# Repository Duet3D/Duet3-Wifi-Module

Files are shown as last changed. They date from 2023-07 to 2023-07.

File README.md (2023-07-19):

# Duet3 Wifi Module
Plugin wifi module for Duet 3 6HC mainboards



Product Page:
[https://www.duet3d.com/duet3_wifi_module](https://www.duet3d.com/duet3_wifi_module)

Documentation is here:

[Duet 3 Wifi Module Documentation](https://docs.duet3d.com/Duet3D_hardware/Duet_3_family/Duet_3_Mainboard_6HC_Hardware_Overview#wifi-v102)

licensed under the "CERN-OHL-S v2" or any later version plus the "Additional Duet3D Licence Terms",
see https://github.com/Duet3D/Duet3-Mainboard-6HC/blob/master/LICENSE

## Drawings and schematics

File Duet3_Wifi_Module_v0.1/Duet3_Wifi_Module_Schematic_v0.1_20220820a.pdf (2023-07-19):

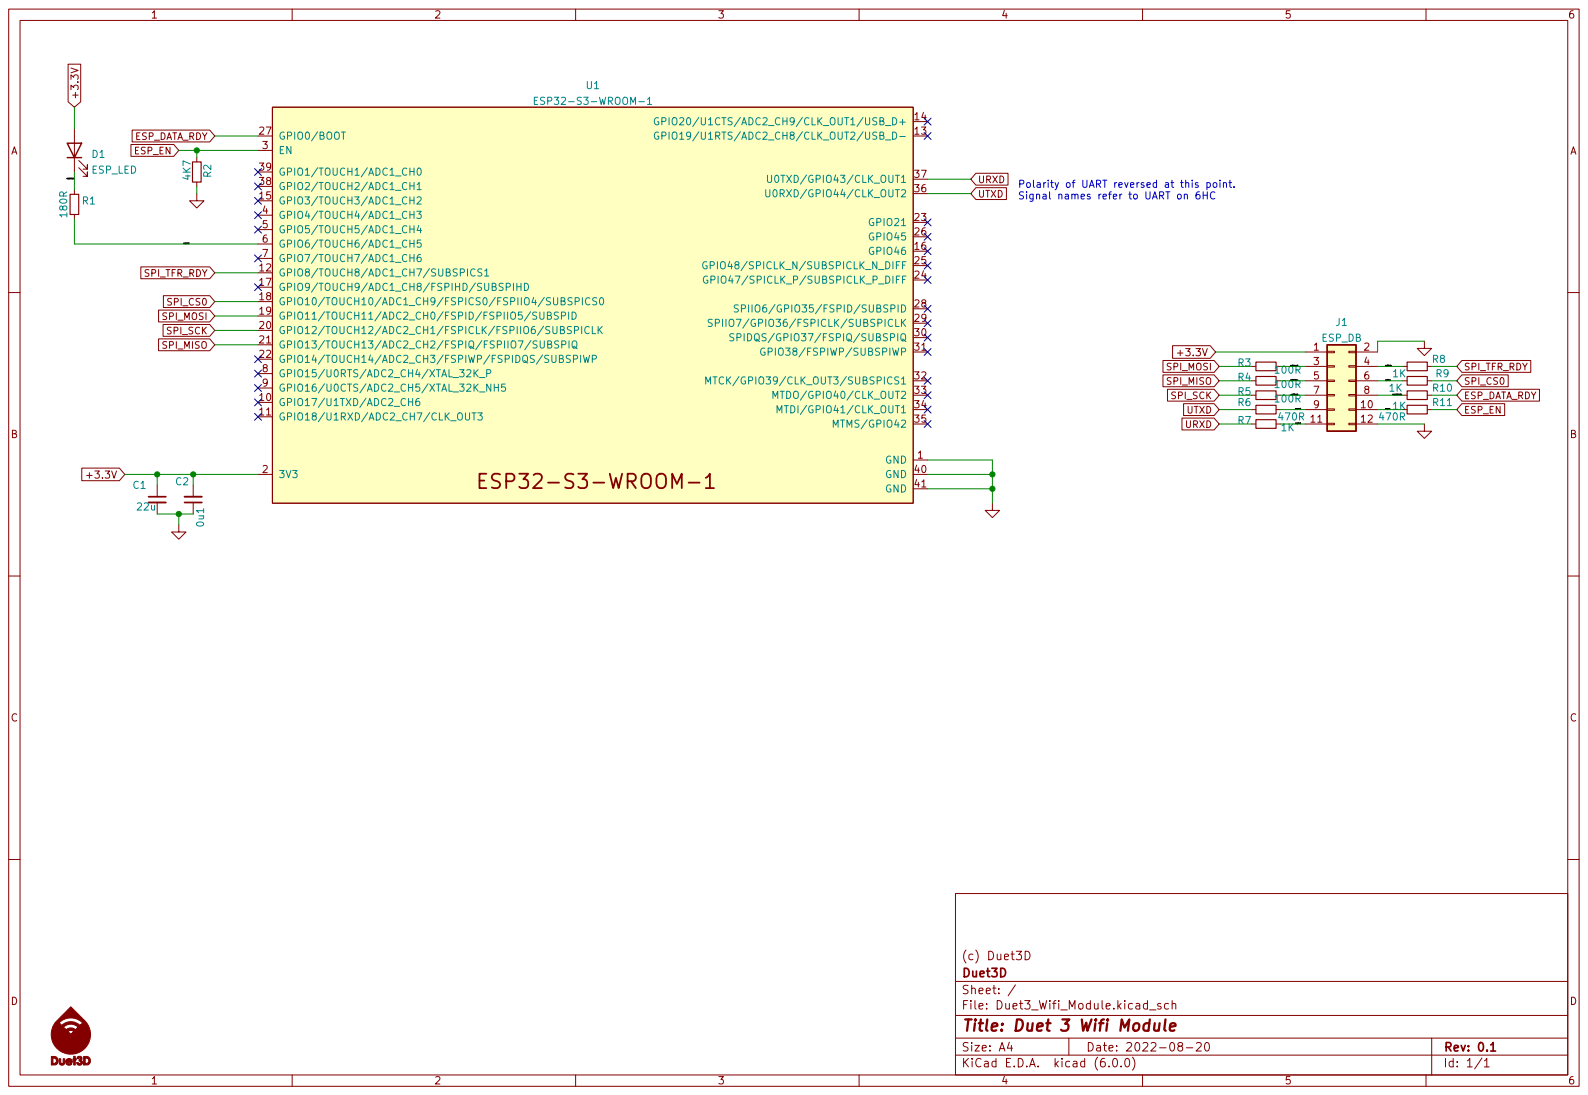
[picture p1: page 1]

spi1mosi Polarity of UART reversed at this point.
Signal names refer to UART on 6HC

Id: 1/1 Title: Duet 3 Wifi Module

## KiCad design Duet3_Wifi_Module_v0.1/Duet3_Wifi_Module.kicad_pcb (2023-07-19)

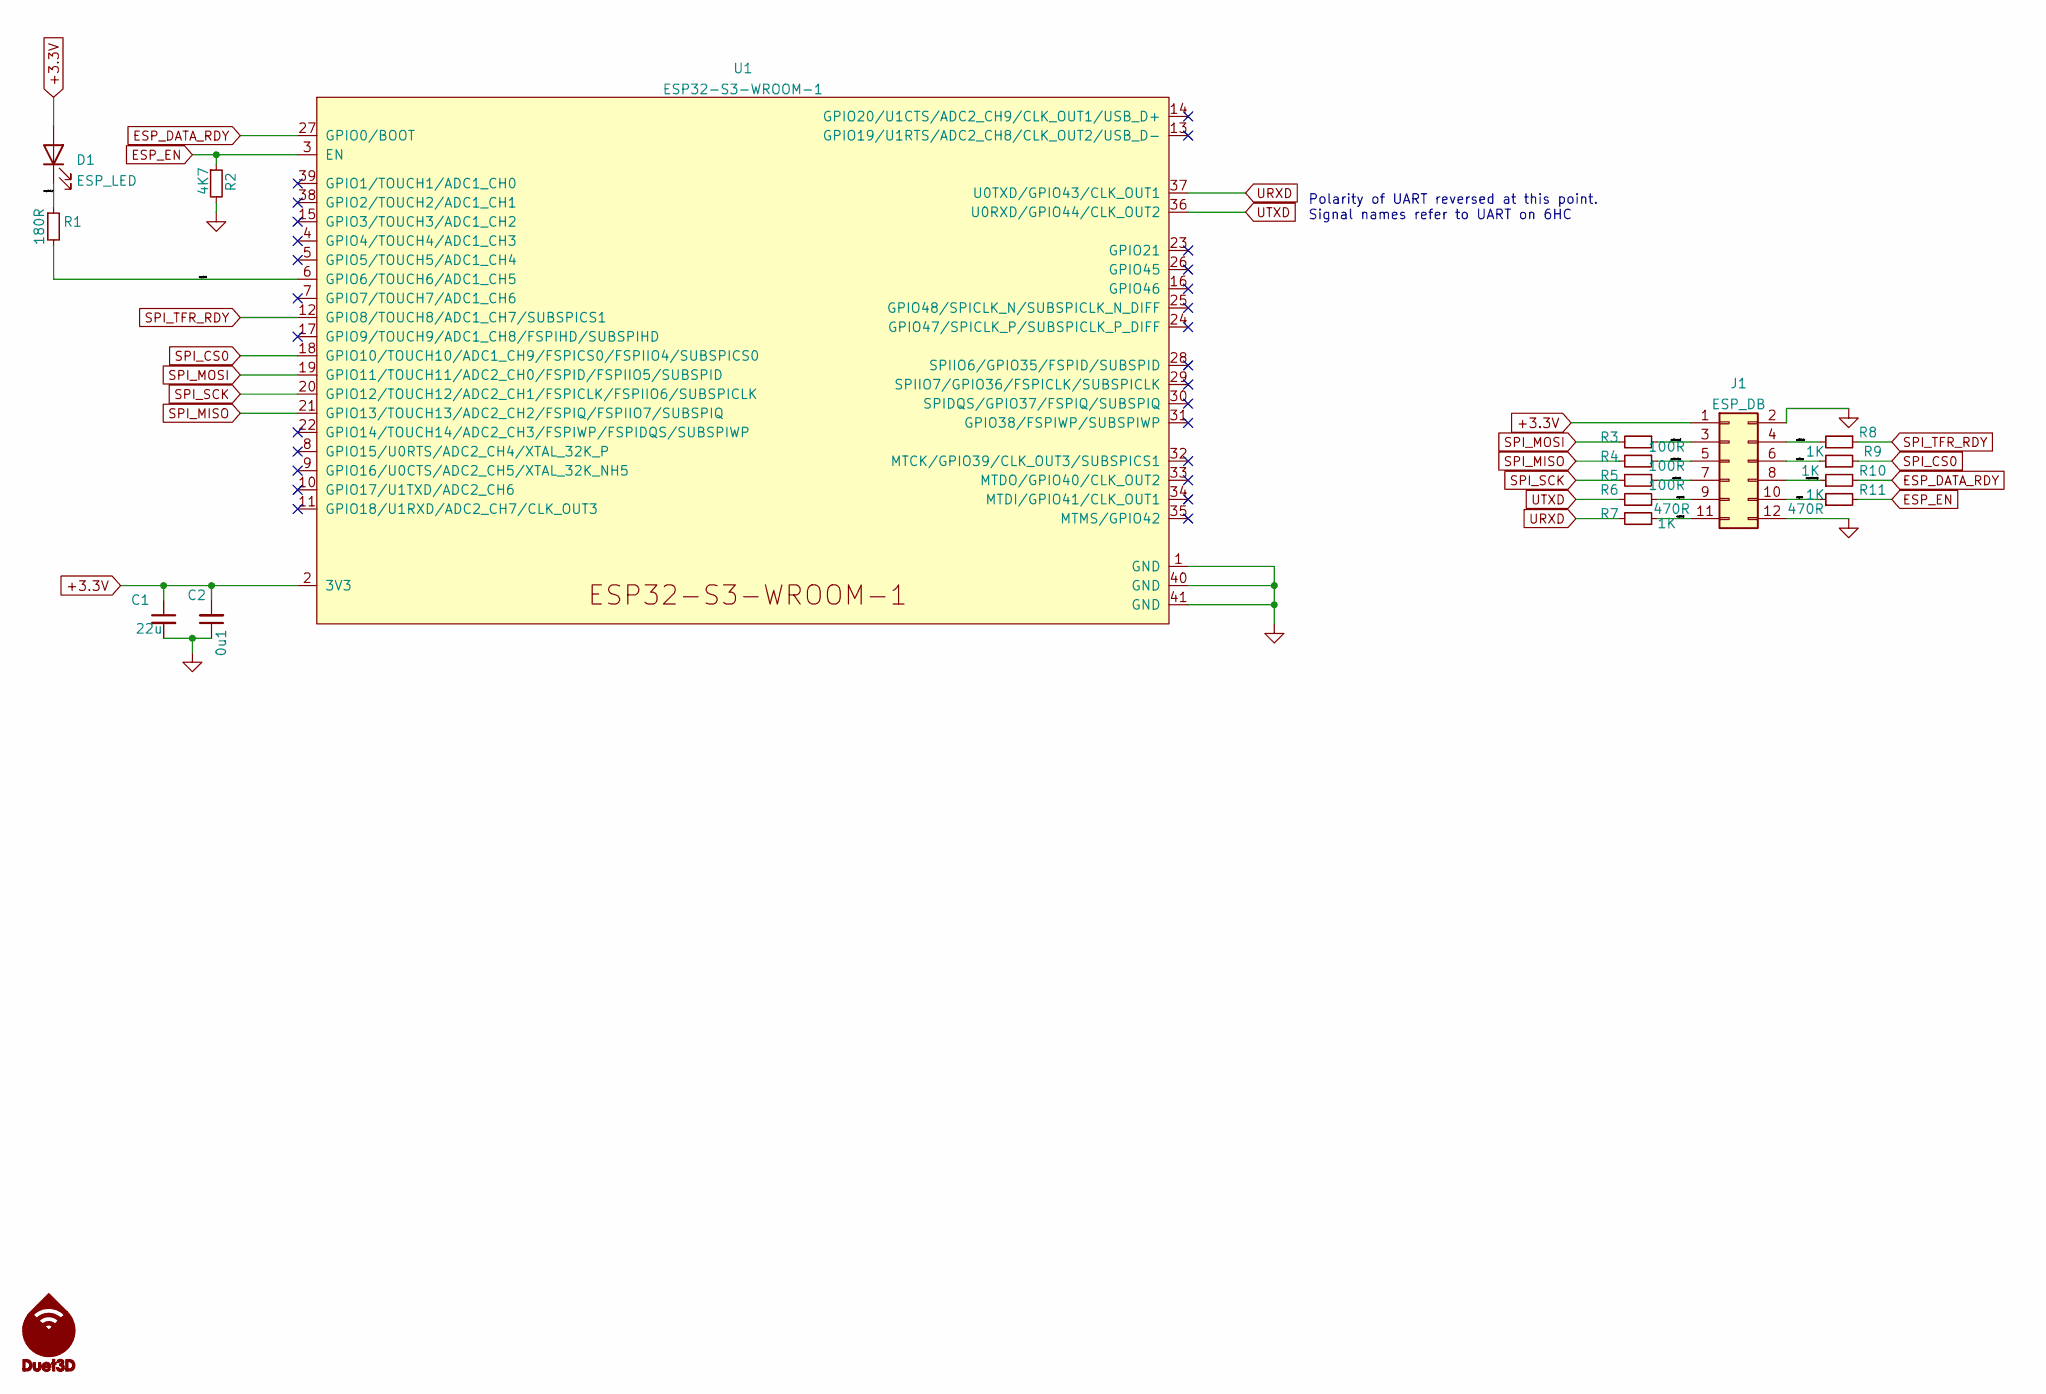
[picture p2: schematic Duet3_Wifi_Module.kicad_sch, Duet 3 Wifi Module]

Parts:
C1: 22u; C_0805_2012Metric; Part Number CL21A226MOQNNNE
C2: 0u1; C_0402_1005Metric_Wbry; Part Number CL05A104KP5NNNC
D1: ESP_LED; LED_0603_1608Metric; Part Number 150060VS75000 or equivalent Green
J1: ESP_DB; PinSocket_2x06_P2.54mm_Vertical
M1: Logo_Duet3d_New; LOGO_NEW_Duet3D_vertical_6mm; Part Number Virtual Component DNP
R1: 180R; R_0402_1005Metric_Wbry; Part Number RMCF0402FT180R
R2: 4K7; R_0402_1005Metric_Wbry; Part Number RK73H1ETTP4701F
R3, R4, R5: 100R; R_0402_1005Metric_Wbry; Part Number RK73H1ETTP1000F
R6, R11: 470R; R_0402_1005Metric_Wbry; Part Number RK73H1ETTP4700F
R7, R8, R9, R10: 1K; R_0402_1005Metric_Wbry; Part Number RK73H1ETTP1001F
U1: ESP32-S3-WROOM-1; ESP32-S3-WROOM-1U

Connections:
+3.3V: C1.1, C2.2, D1.2 (A), J1.1, U1.2 (3V3)
/espdatardy: J1.8, R10.1
/espen: J1.10, R11.1
/espled: R1.2, U1.6 (GPIO6/TOUCH6/ADC1_CH5)
/espled_r: D1.1 (K), R1.1
/esprxd: J1.9, R6.1
/esptxd: J1.11, R7.1
/spi1miso: J1.5, R4.1
/spi1mosi: J1.3, R3.1
/spi1sck: J1.7, R5.1
/spi1ss: J1.6, R9.1
/spitfrdy: J1.4, R8.2
ESP_DATA_RDY: R10.2, U1.27 (GPIO0/BOOT)
ESP_EN: R2.1, R11.2, U1.3 (EN)
GND: C1.2, C2.1, J1.2, J1.12, R2.2, U1.1 (GND), U1.40 (GND), U1.41 (GND)
SPI_CS0: R9.2, U1.18 (GPIO10/TOUCH10/ADC1_CH9/FSPICS0/FSPIIO4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)
SPI_MISO: R4.2, U1.21 (GPIO13/TOUCH13/ADC2_CH2/FSPIQ/FSPIIO7/S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)
SPI_MOSI: R3.2, U1.19 (GPIO11/TOUCH11/ADC2_CH0/FSPID/FSPIIO5/S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)
SPI_SCK: R5.2, U1.20 (GPIO12/TOUCH12/ADC2_CH1/FSPICLK/FSPIIO6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)
SPI_TFR_RDY: R8.1, U1.12 (GPIO8/TOUCH8/ADC1_CH7/SUBSPICS1)
URXD: R7.2, U1.37 (U0TXD/GPIO43/CLK_OUT1)
UTXD: R6.2, U1.36 (U0RXD/GPIO44/CLK_OUT2)

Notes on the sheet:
Polarity of UART reversed at this point. Signal names refer to UART on 6HC

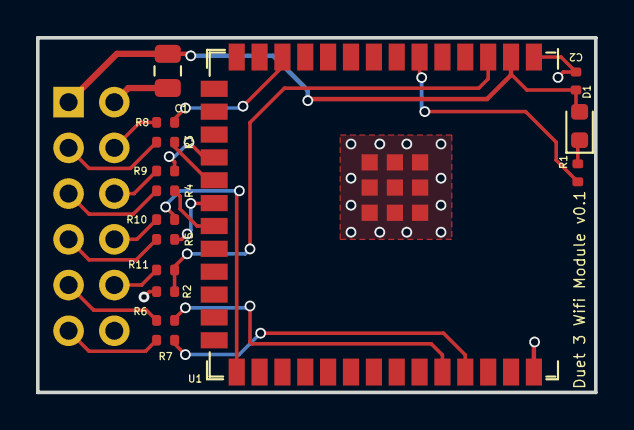
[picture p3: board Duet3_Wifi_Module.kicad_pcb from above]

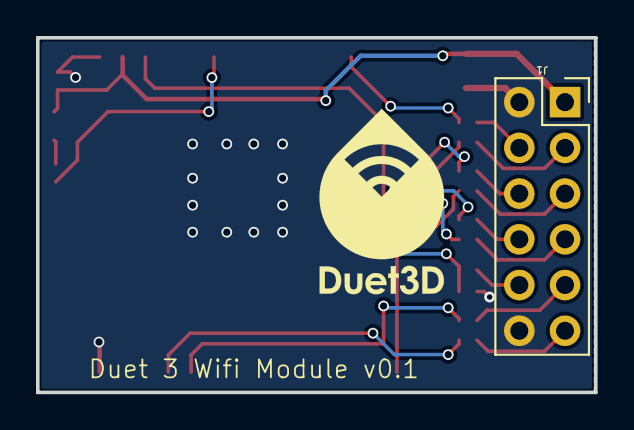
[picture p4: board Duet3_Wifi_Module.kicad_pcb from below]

Board: 2 copper layers, 31.0 x 19.7 mm, 17 parts (2 on the bottom side), 22 nets.
